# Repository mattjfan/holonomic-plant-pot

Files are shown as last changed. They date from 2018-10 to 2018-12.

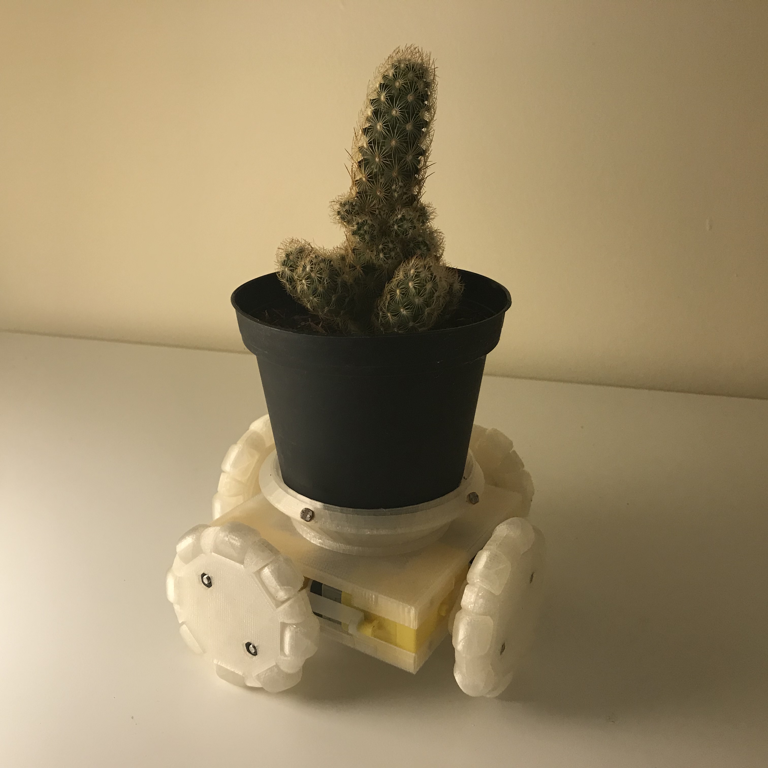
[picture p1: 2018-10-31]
img/Photo Oct 31, 6 10 04 PM.jpg

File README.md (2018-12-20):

# holonomic-plant-pot
Holonomic Light-Seeking Robotic Plant Pot
Holonomic Plant Pot

## Navigation
- [Tutorial](/docs/TUTORIAL.md)
- [CAD](/cad)
- [Schematics](/schematics)
- [Code](/code)
    - [Firmware](/code/omni_plant_pot)
    - [Visualization](/code/processing)
- [Journal](/docs/JOURNAL.md)

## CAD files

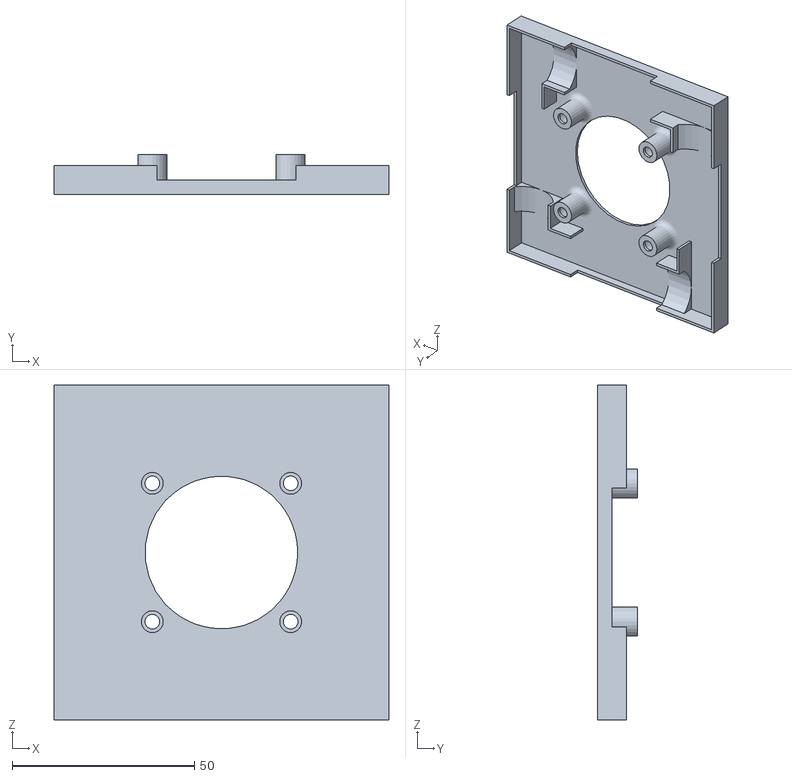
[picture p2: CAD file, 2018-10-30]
cad/mounting/motor_mount_base2_template.stl
92.0 x 11.0 x 92.0

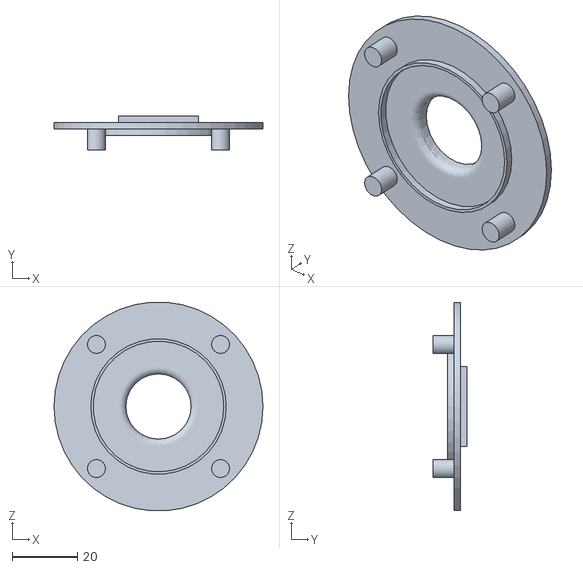
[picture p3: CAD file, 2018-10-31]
cad/mounting/pot/pot_base_adapter2.stl
64.0 x 10.5 x 63.8

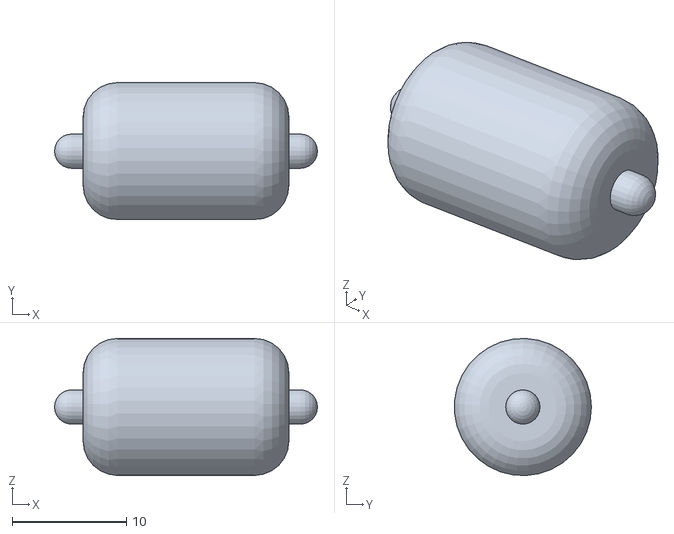
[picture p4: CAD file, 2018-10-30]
cad/omni_roller.stl
23.0 x 12.0 x 12.0

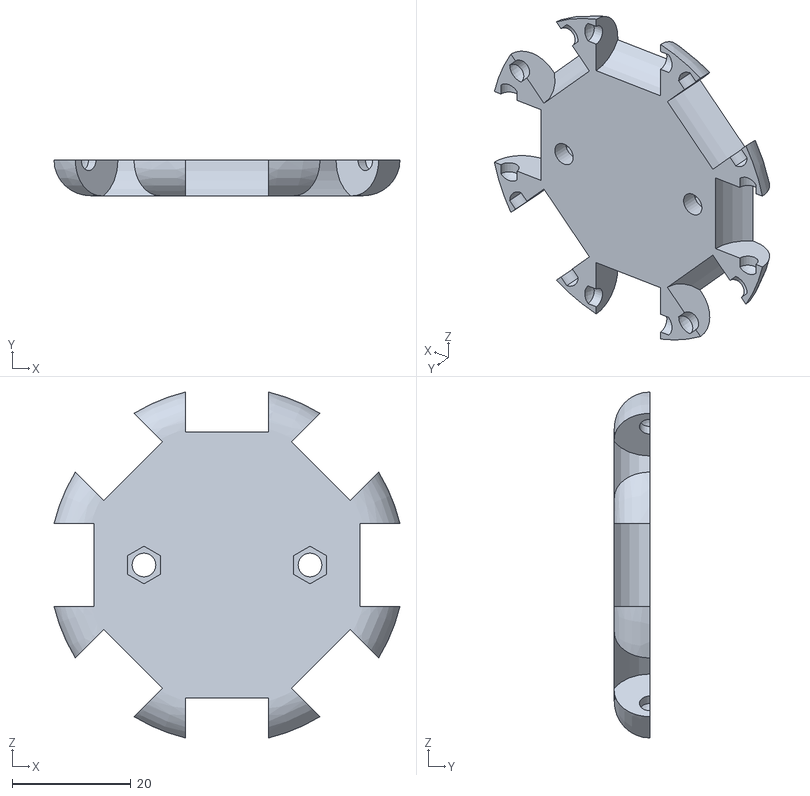
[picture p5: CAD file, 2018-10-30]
cad/omni_wheel_v3/omni_wheel_cover_out_v3.stl
58.3 x 6.00 x 58.3

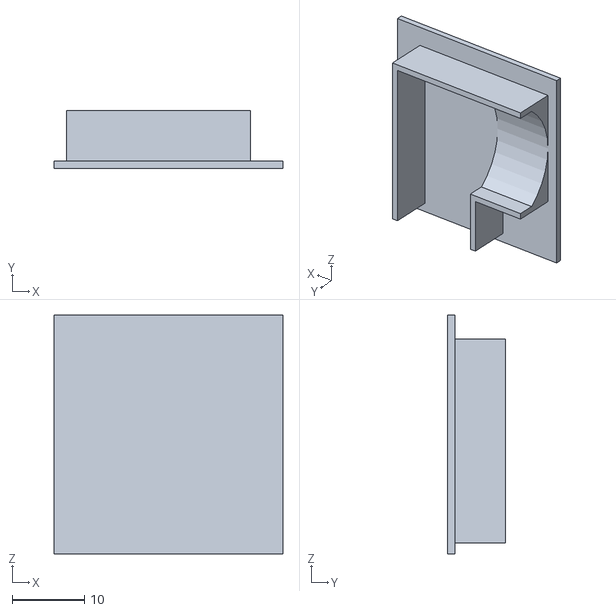
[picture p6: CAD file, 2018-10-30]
cad/mounting/motor_mount_fitcheck1.stl
31.7 x 8.00 x 33.0

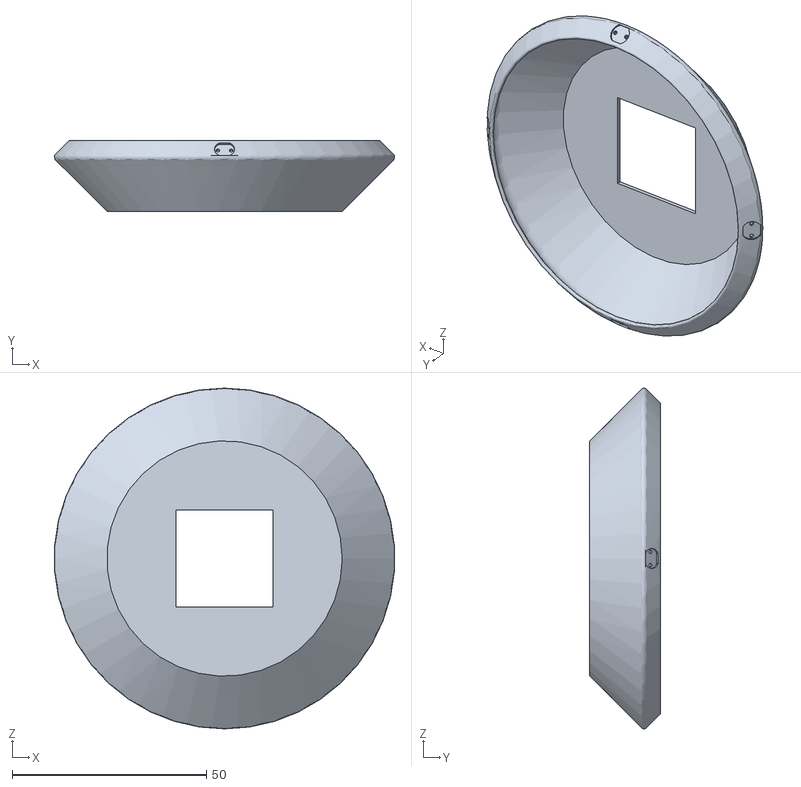
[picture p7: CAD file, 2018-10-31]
cad/mounting/pot/sensor_holder.stl
87.6 x 18.2 x 87.8

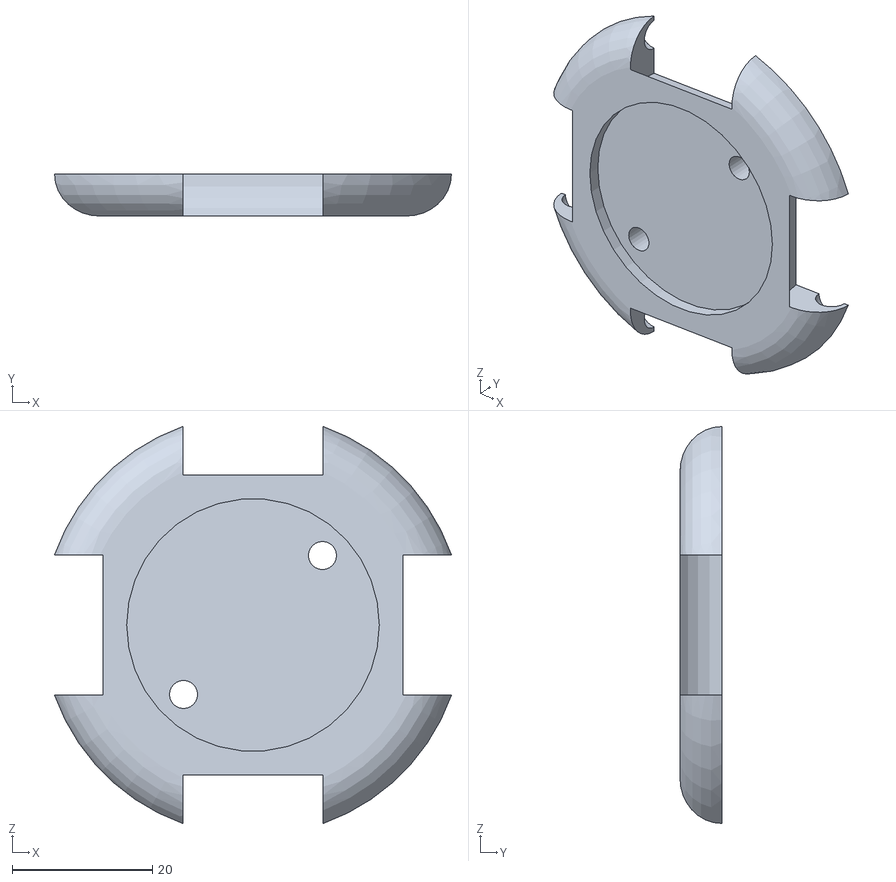
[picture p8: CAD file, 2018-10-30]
cad/omni_wheel_cover_in.stl
56.6 x 6.00 x 56.6

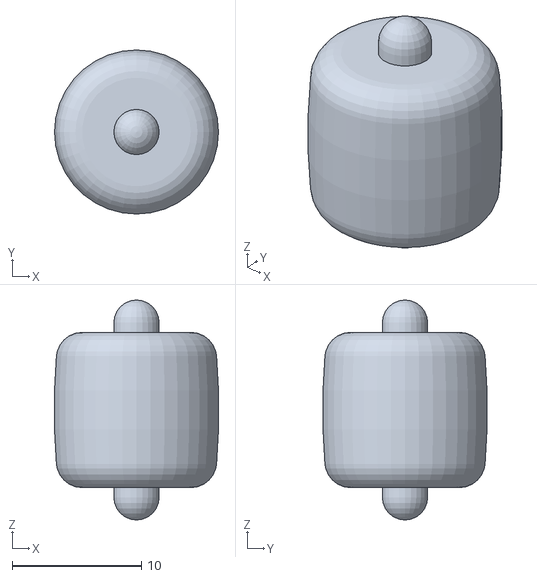
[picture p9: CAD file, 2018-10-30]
cad/omni_wheel_v3/omni_roller_v3.stl
12.7 x 12.7 x 17.0

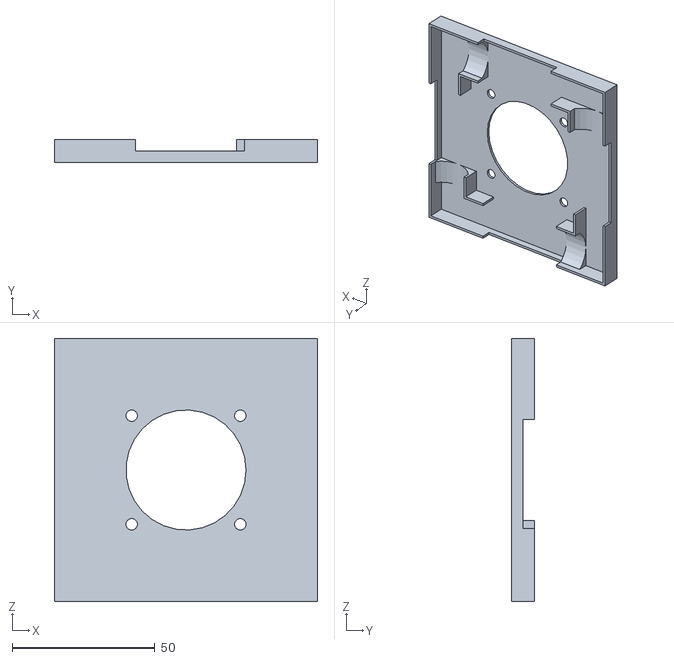
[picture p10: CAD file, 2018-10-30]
cad/mounting/motor_mount_base2_bottom.stl
92.0 x 8.00 x 92.0

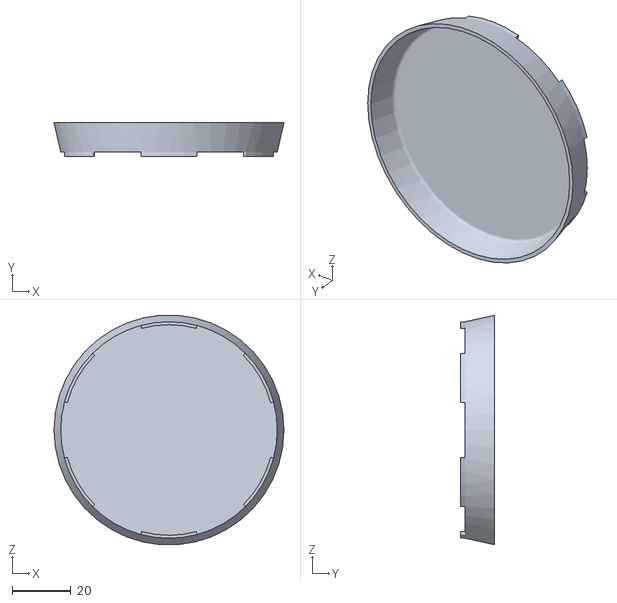
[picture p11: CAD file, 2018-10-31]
cad/mounting/pot/pot_holder_prototype.stl
78.6 x 11.5 x 78.4

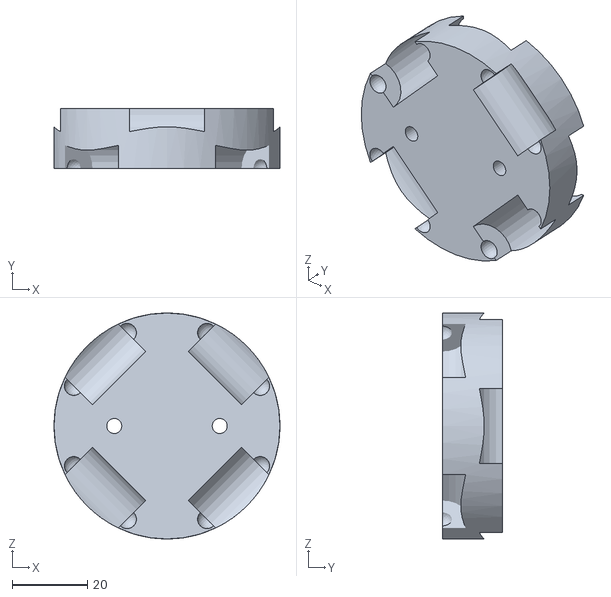
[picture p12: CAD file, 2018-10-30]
cad/omni_wheel_core_1.stl
60.0 x 16.0 x 60.0

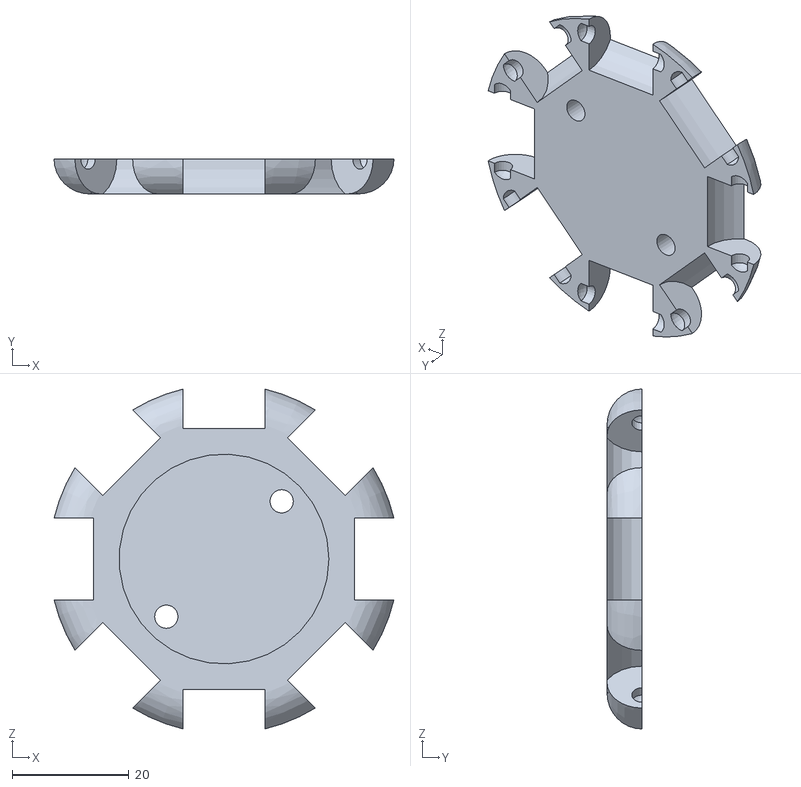
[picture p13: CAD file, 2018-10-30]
cad/omni_wheel_v3/omni_wheel_cover_in_v3.stl
58.3 x 6.00 x 58.3

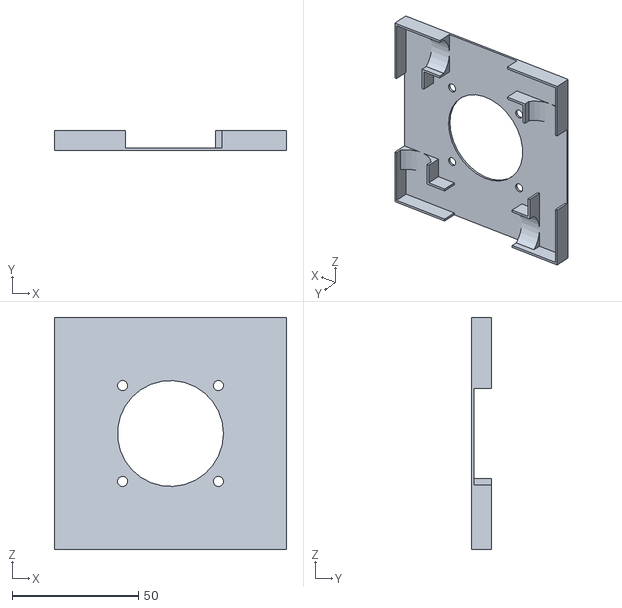
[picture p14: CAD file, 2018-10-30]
cad/mounting/motor_mount_base1_template.stl
92.0 x 8.00 x 92.0

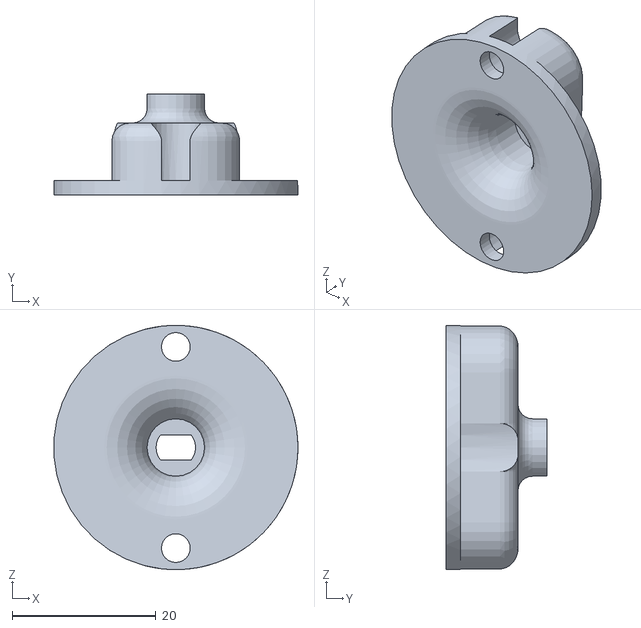
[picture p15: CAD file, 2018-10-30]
cad/omni_wheel_v3/wheel_mount_v3.stl
34.0 x 14.0 x 34.0

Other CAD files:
cad/wheel_mount.stl
cad/omni_wheel_cover_out.sl.stl
cad/omni_wheel_v2/omni_roller_v2.stl
cad/omni_wheel_v2/omni_wheel_cover_out.stl
cad/OldVersions/wheel_core_1.0002.ipt
cad/OldVersions/wheel_cover_in.0001.ipt
cad/OldVersions/wheel_cover_out.0001.ipt
cad/mounting/OldVersions/motor_mount_base1_template.0002.ipt
cad/mounting/OldVersions/motor_mount_base2_bottom.0001.ipt
cad/mounting/OldVersions/motor_mount_base2_template.0001.ipt
cad/mounting/OldVersions/motor_mount_fitcheck1.0001.ipt
cad/mounting/motor_mount_base1_template.ipt
cad/mounting/motor_mount_base2_bottom.ipt
cad/mounting/motor_mount_base2_template.ipt
cad/mounting/motor_mount_fitcheck1.ipt
cad/mounting/pot/OldVersions/pot__assembly_test_v1.0001.iam
cad/mounting/pot/OldVersions/pot_base_adapter2.0001.ipt
cad/mounting/pot/OldVersions/pot_holder_prototype.0002.ipt
cad/mounting/pot/OldVersions/sensor_holder.0002.ipt
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

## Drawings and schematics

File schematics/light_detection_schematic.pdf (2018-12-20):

# Light-Detection Board Schematic

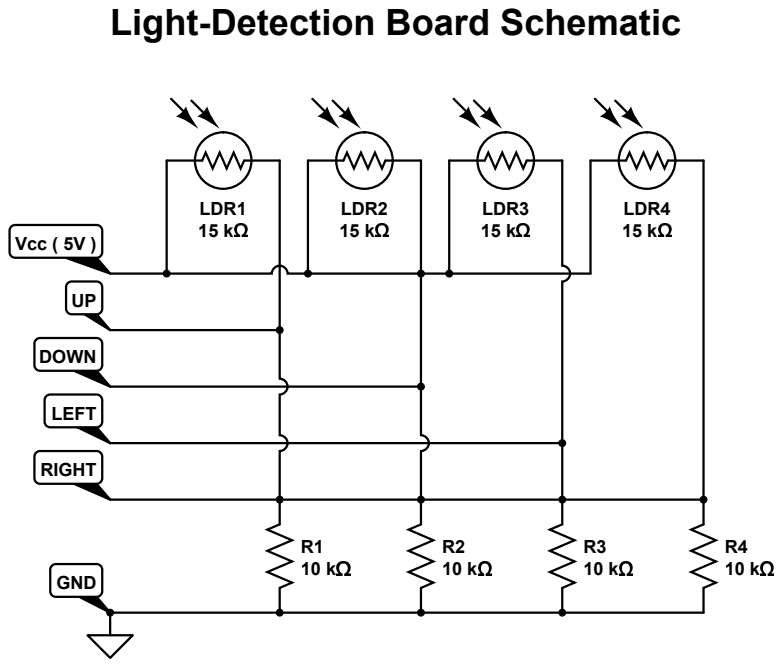
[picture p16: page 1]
LDR1 15 k; LDR2 15 k; LDR3 15 k; LDR4 15 k; Vcc ( 5V ); GND; DOWN; LEFT; RIGHT

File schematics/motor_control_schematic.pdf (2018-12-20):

# Motor Control Board Schematic

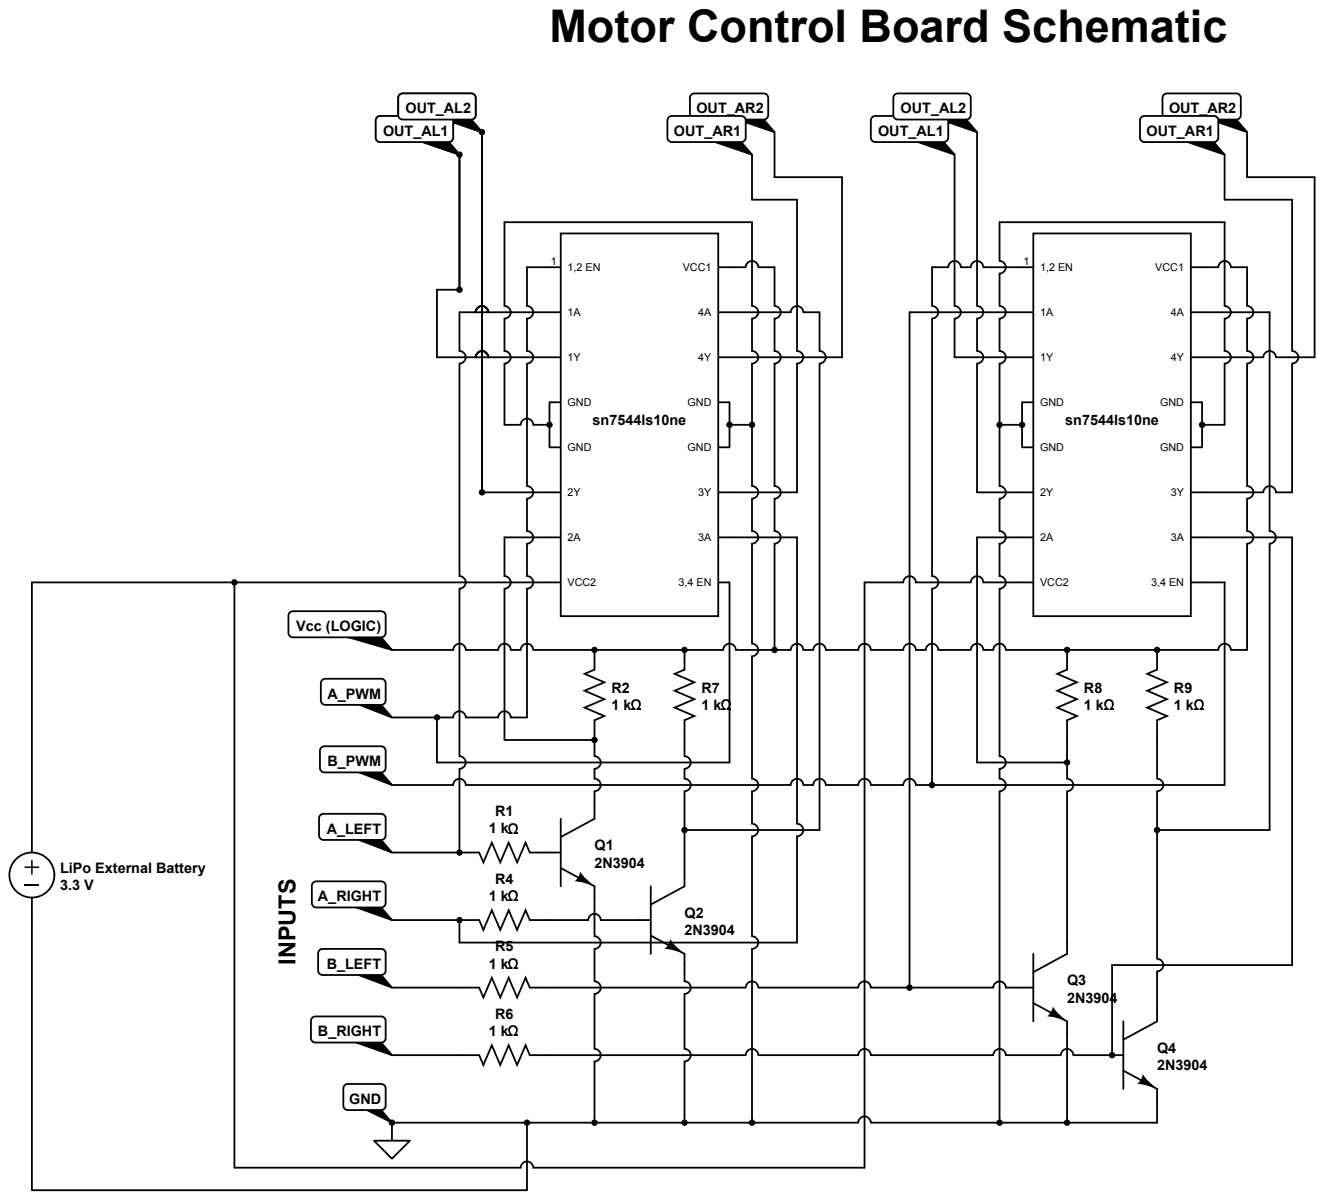
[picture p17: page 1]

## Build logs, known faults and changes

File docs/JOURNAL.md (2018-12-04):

# Build Journal
Wanted to try this new thing of keeping a markdown journal for my projects. We'll see how this goes.

## 11/2/18
Decided to start maintaining this Journal. Officially, I started the build last week (10/26/18). The prints for the first prototype, and some of the code, have already finished, and been assembled. Currently working on putting together the electronics. I started with a resistor pull-down board to connect to the light-sensing array, but accidentally neglected to include the reading wires on the board ☹ Will need to either adjust the designs, or redo the board.

## 11/23/18
Soldered the motor controller board. Was able to get movement, but sporadically. Could be an issue with wires crossing, or not enough current.

## 12/1/18
Trying to finish by Monday. Resoldered the light-sensing board. Getting intermittent connection issues, with some of the inputs zeroing out. My suspicion is that it's an issue with the easy-connect wire terminals. Was still able to get a proof of concept out, testing basic light source detection through processing. Got the entire set-up connected.

Planning on running the first full-system test by EOD tonight.
Was able to get some simple motion, but now I'm getting nothing from the wheel base. Will check again tomorrow.

Still need to build a tether for more comprehensive systems tests.
Also, will need to build the solder the attiny control board if I want it to run untethered.

## 12/2/18
Update: It's currently 1:47 AM. I identified an issue in the motor control board, in that I forgot to connect the pwm control pins on for the h-bridge pairs on each chip. Also, some connections are coming loose again. Will fix this in the morning, and try another systems test.

3:41 AM: Still no luck. Soldered the pwm control pins, but now there's no movement. Seems to be an issue at least with one of the jumpers routing power, as it seems the point where it's soldered is impeding current flow. My guess is that there's some layer built up between the pin and the solder. Will look into it in the morning.

11:01 AM: Fixed on issue on the motor control board with a broken transistor on the right forward control sub-assembly. Also, identified an incorrect transistor used in left strafe control sub-assembly (accidentally mixed in C1815 instead of 2n3904).

12:30 PM: Thought I burnt out another transistor, swapped it out (that's 3/4 transistors swapped). After I made the switch, noticed that the inverting wire from the collector was actually soldered to the base. Swapped it out, and was able to get movement. Will do a full systems test in an hour.

3:09 PM: Ran another movement test. Was able to get motion in forward and backwards directions, however the direction enums aren't properly corresponding to the output directions. Furthermore, after additional testing, enums aren't able to produce an output state corrsponding to a left turn (CAN do forward, backwards, and right). Also, brake command doesn't seem to work after prolonged use, and I think I saw motors reverse without command. This is only with subsystem A. Will try for subsystem B, and log results as well.

3:16 PM: Subsystem B test is succesful, and operational (turns might be inverted, but we can fix that n the code). Seems likely that there's something wrong with subsystem A. 

3:38 PM: Noticed unintended contact between two solder traces. Used a razor to seperate the traces, and both subsystems are operational!

3:42 PM: 💩 One of the motor terminals snapped off.

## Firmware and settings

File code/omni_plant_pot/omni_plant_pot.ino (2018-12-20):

// Holonomic Light-Seeking Plant Pot
// Copyright 2018 Matthew Fan

// pinouts for motor control
#define AP 3
#define AL 4
#define AR 5
#define BP 10
#define BL 9                                                                                                                                                                                                                                                                                                                                                                                                                                                                                                                                                                                                                                                                                                                                                                                                                                                                                                                                                                                                                                                                                                                                                                                                                                                                                                                                                                                                                                                                                                                                                                                                                                                                                                                                                                                                                                                                                                                                                                                                                                                                                                                                                                                                                                                                                                                                                                                                                                                                                                                                                                                                                                                                                                                                                                                                                                                                                                                                                                                                                                                                                                                                                                                                                                                                                                                                                                                                                                                                                                                                                                                                                                                                                                                                                                                                                                                                                                                                                                                                                                                                                                                                                                                                                                                                                                                                                                                                                                                                                                                                                                                                                                                                                                                                                                                                                                                                                                                                                                                                                                                                                                                                                                                                                                                                                                                                                                                                                                                                                                                                                                                                                                                                                                                                                                                                                                                                  
#define BR 8
#define WHISTLE 1

#define AL1 4
#define AL2 5
#define AR1 6
#define AR2 7

#define BL1 9
#define BL2 8
#define BR1 11
#define BR2 12
// analog sensing pins in for light sensing
#define L_U 0
#define L_D 1
#define L_L 2
#define L_R 3

// named constants
#define FORWARD 1
#define BACKWARD 2
#define LEFT 3
#define RIGHT 4

int light_up, light_down, light_left, light_right;

void update_photocells() {
  light_up = analogRead(L_U);
  light_down = analogRead(L_D);
  light_left = analogRead(L_L);
  light_right = analogRead(L_R); 
}

void set_direction_DEPRECATED( char group, int dir){
  //deprecated 2-pin version
  int left, right;
  // Set pins to corresponding group.
  if (group == 'A'){
    left = AL;
    right = AR;
  }
  if (group == 'B'){
    left = BL;
    right = BR;
  }
//  Serial.print("Left pin is ");
//  Serial.println((String) left);
//  Serial.print("Right pin is ");
//  Serial.println((String) right);
  // Writing the corresponding direction pins as desired
  switch(dir){
    case FORWARD:
//      Serial.println("forwards");
      digitalWrite(left, HIGH);
      digitalWrite(right, HIGH);
      break;
    case BACKWARD:
//      Serial.println("backwards");
      digitalWrite(left, LOW);
      digitalWrite(right, LOW);
      break;
    case LEFT:
//      Serial.println("left");
      digitalWrite(left, LOW);
      digitalWrite(right, HIGH);
      break;
    case RIGHT:
//      Serial.println("right");
      digitalWrite(left, HIGH);
      digitalWrite(right, LOW);
      break; //why not
    default: break;
  }
}

void set_direction( char group, int dir){
  //new version with 4 pin explicit output
  int l1, l2, r1, r2;
  // Set pins to corresponding group.
  if (group == 'A'){
    l1 = AL1;
    l2 = AL2;
    r1 = AR1;
    r2 = AR2;
  }
  if (group == 'B'){
    l1 = BL1;
    l2 = BL2;
    r1 = BR1;
    r2 = BR2;
  }
//  Serial.print("Left pin is ");
//  Serial.println((String) left);
//  Serial.print("Right pin is ");
//  Serial.println((String) right);
  // Writing the corresponding direction pins as desired
  switch(dir){
    case FORWARD:
//      Serial.println("forwards");
      digitalWrite(l1, HIGH);
      digitalWrite(r1, HIGH);
      digitalWrite(l2, LOW);
      digitalWrite(r2, LOW);
      break;
    case BACKWARD:
//      Serial.println("backwards");
      digitalWrite(l1, LOW);
      digitalWrite(r1, LOW);
      digitalWrite(l2, HIGH);
      digitalWrite(r2, HIGH);
      break;
    case LEFT:
//      Serial.println("left");
      digitalWrite(l1, LOW);
      digitalWrite(r1, HIGH);
      digitalWrite(l2, HIGH);
      digitalWrite(r2, LOW);
      break;
    case RIGHT:
//      Serial.println("right");
      digitalWrite(l1, HIGH);
      digitalWrite(r1, LOW);
      digitalWrite(l2, LOW);
      digitalWrite(r2, HIGH);
      break; //why not
    default: break;
  }
}

void set_power( char group, int power) {
  // somewhat unnecessary abstraction, but I'll include for consistency with interface.
//  Serial.println((String)group);
  if (group == 'A'){
//    Serial.print("Setting A power to ");
//    Serial.println((String)power);
    analogWrite(AP, power);
  }
  if (group == 'B'){
//    Serial.print("Setting B power to ");
//    Serial.println((String)power);
    analogWrite(BP, power);
  }
}

void set_motor_group( char group, int dir, int power){
  set_direction(group, dir);
  set_power(group, power);
  
  
}

void holonomic_seek_step(){
  // Set the the bot to holonomically seek the light source at the specific instance in time
  // Should be wrapped in a control block to adjust precision
  update_photocells();
  int y_diff = ((light_up - light_down) * 255) / 1023;
  int x_diff = ((light_right - light_left) * 255) / 1023;
  int y_mag = abs(y_diff);
  int x_mag = abs(x_diff);
  if (y_mag > x_mag){
    x_mag = 255 * x_mag / y_mag;
    y_mag = 255;
  } else if (x_mag > y_mag){
   y_mag = 255 * y_mag / x_mag;
   x_mag = 255;
  }
  if (y_diff > 0) {
    set_motor_group('A', FORWARD, y_mag);
  } else {
    set_motor_group('A', BACKWARD, y_mag);
  }
  if (x_diff > 0) {
    set_motor_group('B', FORWARD, x_mag);
  } else {
    set_motor_group('B', BACKWARD, x_mag);
  }  
}

int ambient_light(){
  update_photocells();
  return min(min(light_up, light_down), min(light_left, light_right));
}



void rotational_seek_step_fine(){
  // Set the the bot to rotationally seek the light source at the specific instance in time
  // Should be wrapped in a control loop
  update_photocells();
  int forward = light_up;
  set_motor_group('A', LEFT, 255);
  set_motor_group('B', LEFT, 255);
  delay(100);
  update_photocells();
  int left = light_left;
  set_motor_group('A', RIGHT, 255);
  set_motor_group('B', RIGHT, 255);
  delay(200);
  update_photocells();
  int right = light_right;
  if (forward > right){
      set_motor_group('A', LEFT, 255);
      set_motor_group('B', LEFT, 255);
      delay(100);
  }
   if (left > forward){
      set_motor_group('A', LEFT, 255);
      set_motor_group('B', LEFT, 255);
      delay(100);
  }
}
boolean rotational_seek_step_coarse(){
  // Set the the bot to rotationally seek the light source at the specific instance in time
  // Should be wrapped in a control loop
  update_photocells();
  if (light_left > light_right){
    if (light_up < light_left) {
      set_motor_group('A', LEFT, 255);
      set_motor_group('B', LEFT, 255);
      delay(100);
      return true;
    }
  } else {
    if (light_up < light_right) {
      set_motor_group('A', RIGHT, 255);
      set_motor_group('B', RIGHT, 255);
      delay(100); 
      return true;    
    }    
  }
  return false;
}

void holonomic_seek(int threshold, int step_length){
  while (ambient_light() < threshold){
    holonomic_seek_step();
    delay(step_length);
  }
}

void rotational_seek(int threshold) {
  while (ambient_light() < threshold) {
    while(rotational_seek_step_coarse() == true){}
    for (int i = 0; i < 20; i++){
      rotational_seek_step_fine(); //fine correction
    }
    set_motor_group('A', FORWARD, 255);
    delay(100);
    set_motor_group('A', FORWARD, 0);
  }
}

void set_motors_manual(int power){
   char key;
   if (Serial.available()) {
     key = Serial.read(); 
   }
   switch(key){
    case 'w':
      set_motor_group('A', FORWARD, power);
      set_motor_group('B', FORWARD, 0);
      break;
    case 'a':
      set_motor_group('A', FORWARD, 0);
      set_motor_group('B', BACKWARD, power);
      break;
    case 's':
      set_motor_group('A', BACKWARD, power);
      set_motor_group('B', FORWARD, 0);
      break;
    case 'd':
      set_motor_group('A', FORWARD, 0);
      set_motor_group('B', FORWARD, power);
      break;
    case 'q':
      set_motor_group('A', LEFT, power);
      set_motor_group('B', LEFT, power);
      break;
    case 'e':
      set_motor_group('A', RIGHT, power);
      set_motor_group('B', RIGHT, power);
      break;
    case 'x':
      set_motor_group('A', FORWARD, 0);
      set_motor_group('B', FORWARD, 0);
      break;
    default:
      break;
   }
   delay(10);
}

void brake(){
  set_motor_group('A', FORWARD, 0);
  set_motor_group('B', FORWARD, 0);
}

void bask(){
  set_motor_group('A', LEFT, 80);
  set_motor_group('B', LEFT, 80);
}

/**
 * Send data over to be used in  processing.
 */
void serial_processing(){
//    Serial.print("up: ");
  Serial.print(analogRead(L_U));
  Serial.print("  ");
  Serial.print(analogRead(L_D));
  Serial.print("  ");
  Serial.print(analogRead(L_L));
  Serial.print("  ");
  Serial.println(analogRead(L_R));
  delay(30);
}

void setup() {
  pinMode(AL, OUTPUT);
  pinMode(AR, OUTPUT);
  pinMode(AP, OUTPUT);
  pinMode(BL, OUTPUT);
  pinMode(BR, OUTPUT);
  pinMode(BP, OUTPUT);
  pinMode(AL1, OUTPUT);
  pinMode(AR1, OUTPUT);
  pinMode(AL2, OUTPUT);
  pinMode(AR2, OUTPUT);
  pinMode(BL1, OUTPUT);
  pinMode(BR1, OUTPUT);
  pinMode(BL2, OUTPUT);
  pinMode(BR2, OUTPUT);

  Serial.begin(9600);
  set_motor_group('A', FORWARD, 0);
  set_motor_group('B', FORWARD, 0);
}

void loop() {
//    serial_processing();
//    set_motors_manual(120);
  holonomic_seek(1023, 100);
}

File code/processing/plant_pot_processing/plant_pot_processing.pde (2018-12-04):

import processing.serial.*;

Serial port; 
String val;  

void setup()
{
  String portName = Serial.list()[0];
  port = new Serial(this, portName, 9600);
  size(800, 800);
}

void predict_light_source(int up, int down, int left, int right){
  int x = ((right-left)*400)/1023 + 400;
  int y = ((down-up)*400)/1023 + 400;
  int intensity = ((up+down+left+right)*255)/(1023*4);
  //System.out.println(intensity);
  noStroke();
  background(intensity);
  int max_intensity = max(up,down,max(left,right))*255/1023;
  int b2 = (max_intensity-intensity)/3 + intensity;
  int b1 = ((max_intensity-intensity)*2)/3 + intensity;
  int b0 = max_intensity;
  fill(b2);
  ellipse(x, y, max_intensity, max_intensity);
  fill(b1);
  ellipse(x, y, max_intensity*2/3, max_intensity*2/3);
  fill(b0);
  ellipse(x, y, max_intensity/3, max_intensity/3);
  stroke(255,255,0);
  line(400, 390, 400, 410);
  line(390, 400, 410, 400);
  textSize(20);
  color green = color(30, 255, 0);
  color red = color(255,30,30);
  if (intensity > 128){
    fill(0);
  }else{
    fill(255);
  }
  text("System Health: ", 30, 750); 
  if (up == 0) {
    fill(red);
  } else {
    fill(green);
  }
  text("UP", 200, 750); 
  if (down == 0) {
    fill(red);
  } else {
    fill(green);
  }
  text("DOWN", 260, 750); 
  if (left == 0) {
    fill(red);
  } else {
    fill(green);
  }
  text("LEFT", 360, 750); 
  if (right == 0) {
    fill(red);
  } else {
    fill(green);
  }
  text("RIGHT", 440, 750); 
}
void draw()
{
  if ( port.available() > 0) 
  {  // If data is available,
  String s = port.readStringUntil('\n');
  if (s != null){
      System.out.println(s);
     String[] vals = splitTokens(s.trim(), "  "); //split trimmed input
    if (vals.length == 4) {
      int up = int(vals[0]);
      int down = int(vals[1]);
      int left = int(vals[2]);
      int right = int(vals[3]);
      predict_light_source(up,down,left,right);
    }else{
      background(0,0,255);
      fill(255);
      text("No Connection", 400,400);
    }
  }
  
} 
  
}

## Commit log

2018-10-31 added parts and updated README hero image
    [pot__assembly_test_v1.0001.iam, pot__assembly_test_v1.iam, pot_base_adapter2.0001.ipt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]
2018-12-20 Add schematics and readme navigation
